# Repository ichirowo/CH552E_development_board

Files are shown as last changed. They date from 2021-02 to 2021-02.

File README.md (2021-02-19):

## CH552E development board

This is a development board with [CH552E](http://www.wch-ic.com/products/CH552.html) from Jiangsu Haoheng Co.

It is a multi-functional microcontroller with 4 GPIO pins and supports ADC, PWM, UART, SPI, and USB targets.

LED is connected to P1.4 pin.

A boot button is provided to boot in write mode.

USB TYPE-C connector is used.

If a pin header is attached, it can be used for prototyping on a breadboard.

This board was created with Kicad version 5.1.9.

----

### License

This project is licensed as MIT License.

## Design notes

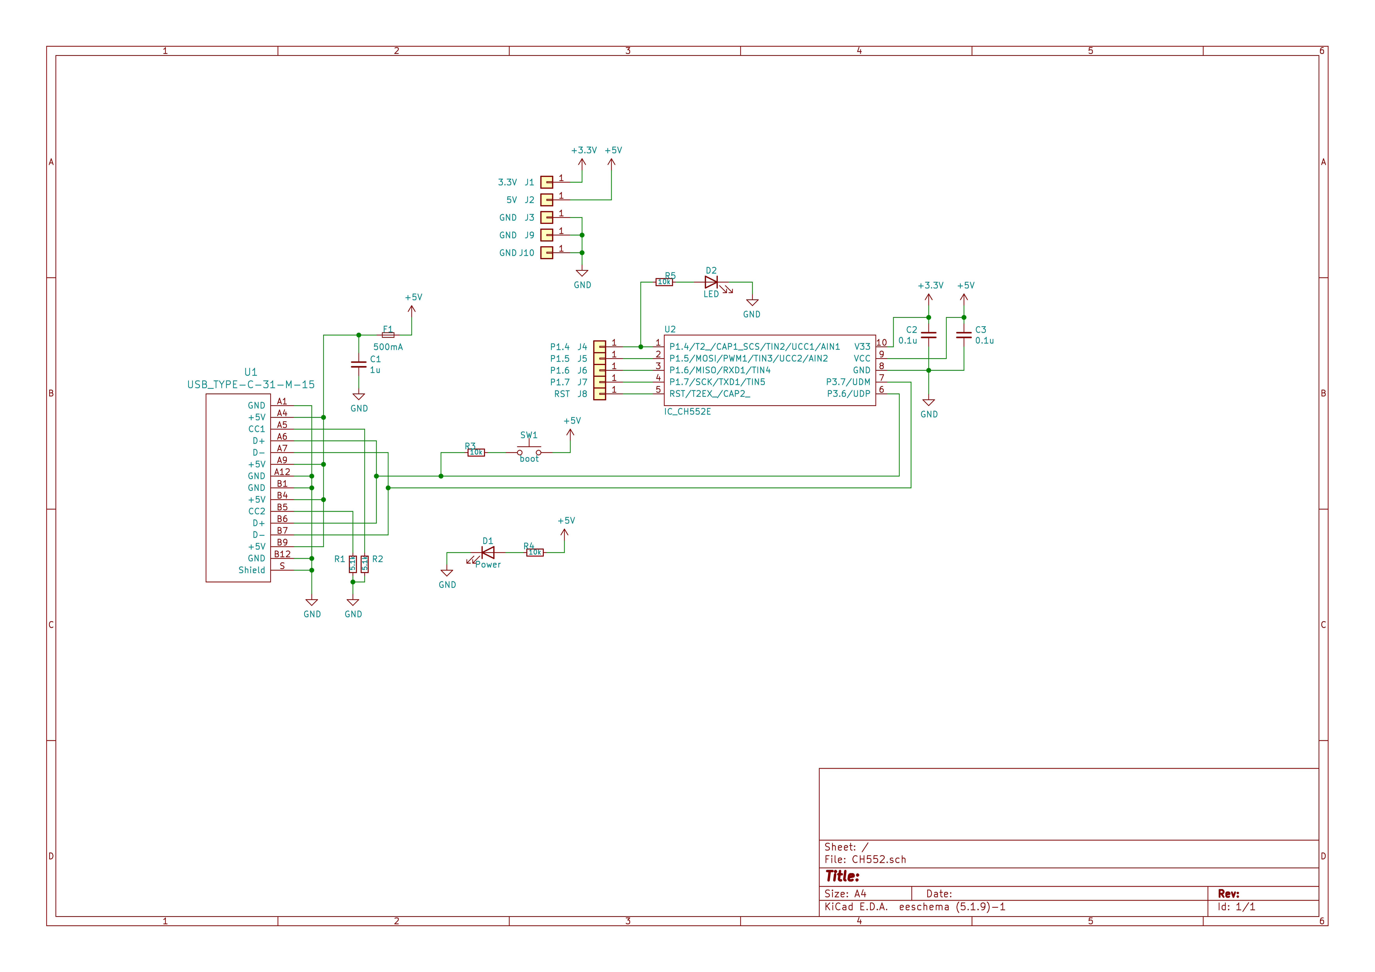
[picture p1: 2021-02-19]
Circuit Diagram.png

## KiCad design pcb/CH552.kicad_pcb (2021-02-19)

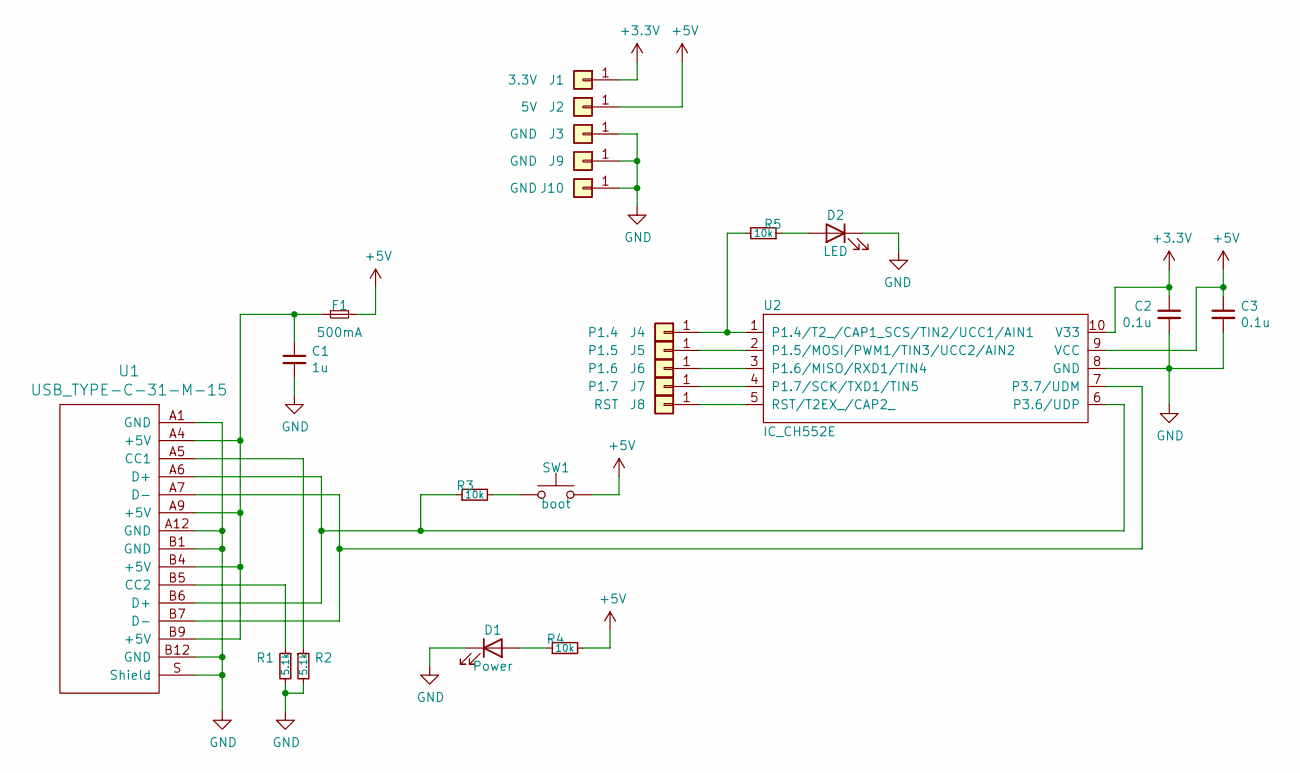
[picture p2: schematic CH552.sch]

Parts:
C1: 1u; C_0603_1608Metric_Pad1.05x0.95mm_HandSolder
C2, C3: 0.1u; C_0603_1608Metric_Pad1.05x0.95mm_HandSolder
D1: Power; LED_0603_1608Metric_Pad1.05x0.95mm_HandSolder
D2: LED; LED_0603_1608Metric_Pad1.05x0.95mm_HandSolder
F1: 500mA; Fuse_0603_1608Metric_Pad1.05x0.95mm_HandSolder
J1: 3.3V; Pad_1P_1.9-1.0
J2: 5V; Pad_1P_1.9-1.0
J3, J9, J10: GND; Pad_1P_1.9-1.0
J4: P1.4; Pad_1P_1.9-1.0
J5: P1.5; Pad_1P_1.9-1.0
J6: P1.6; Pad_1P_1.9-1.0
J7: P1.7; Pad_1P_1.9-1.0
J8: RST; Pad_1P_1.9-1.0
R1, R2: 5.1k; R_0603_1608Metric_Pad0.98x0.95mm_HandSolder
R3, R4, R5: 10k; R_0603_1608Metric_Pad0.98x0.95mm_HandSolder
SW1: boot; PTS810_SJM_250_SMTR_LFS
U1: USB_TYPE-C-31-M-15; USB-C_TYPE-C-31-M-12
U2: IC_CH552E; MSOP-10_3x3mm_P0.5mm

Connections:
+3V3: C2.1, J1.1, U2.10 (V33)
+5V: C3.1, F1.2, J2.1, R4.2, SW1.2, U2.9 (VCC)
GND: C1.2, C2.2, C3.2, D1.1 (K), D2.1 (K), J3.1, J9.1, J10.1, R1.2, R2.2, U1.A1 (GND), U1.A12 (GND), U1.B1 (GND), U1.B12 (GND), U1.S (Shield), U2.8 (GND)
unnamed: C1.1, F1.1, U1.A4 (+5V), U1.A9 (+5V), U1.B4 (+5V), U1.B9 (+5V)
unnamed: D1.2 (A), R4.1
unnamed: D2.2 (A), R5.1
unnamed: J4.1, R5.2, U2.1 (P1.4/T2_/CAP1_SCS/TIN2/UCC1/AIN1)
unnamed: J5.1, U2.2 (P1.5/MOSI/PWM1/TIN3/UCC2/AIN2)
unnamed: J6.1, U2.3 (P1.6/MISO/RXD1/TIN4)
unnamed: J7.1, U2.4 (P1.7/SCK/TXD1/TIN5)
unnamed: J8.1, U2.5 (RST/T2EX_/CAP2_)
unnamed: R1.1, U1.B5 (CC2)
unnamed: R2.1, U1.A5 (CC1)
unnamed: R3.1, U1.A6 (D+), U1.B6 (D+), U2.6 (P3.6/UDP)
unnamed: R3.2, SW1.1
unnamed: U1.A7 (D-), U1.B7 (D-), U2.7 (P3.7/UDM)

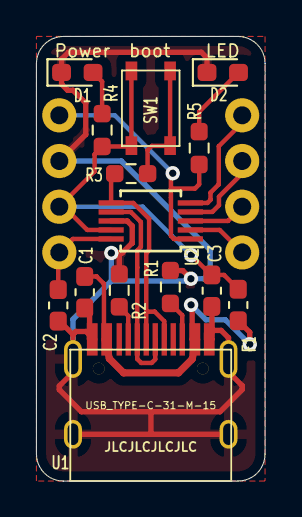
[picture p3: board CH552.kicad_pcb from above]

Board: 2 copper layers, 12.7 x 24.7 mm, 22 parts (0 on the bottom side), 16 nets.
